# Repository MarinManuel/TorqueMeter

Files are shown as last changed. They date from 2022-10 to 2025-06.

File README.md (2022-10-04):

# Torque Meter
A low-cost, Open-Source device to evaluate hypertonia in a rabbit model of cerebral palsy
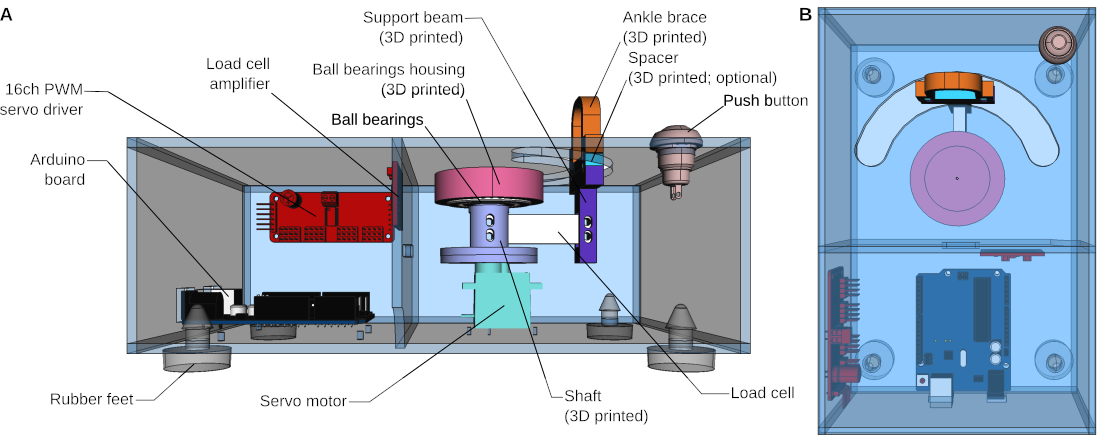
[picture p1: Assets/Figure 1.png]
A 3D model of the finished device


## Files
 - Schematics.fzz - Schematics of the electronics, Fritzing format
 - Schematics.svg - svg export of the above
 - enclosure.svg - file for laser cutter
 - Torque Meter 3D Model.FCStd - CAD files for the hardware.
                                 FreeCAD v.0.20 format
 - 3D print/ - folder containing the STL files for 3D printing the hardware
               components. Exported from the file above
 - Assets/ - contains datasheets and other misc. Files
 - ArduinoTorqueMeter/ - the main Arduino Sketch
 - CalibTorqueMeter/ - Arduino sketch for calibrating the load cell output
 - TorquePlotter/ - Python software for capturing and plotting data from the
                    Torque Meter

## LICENSES
Copyright Preston Steel, Marin Manuel 2022
### Hardware
This source describes Open Hardware and is licensed under the CERN-OHL-S v2.You may redistribute and modify this source and make products using it under the terms of the CERN-OHL-S v2 (https://ohwr.org/cern_ohl_s_v2.txt).This source is distributed WITHOUT ANY EXPRESS OR IMPLIED WARRANTY, INCLUDING OF MERCHANTABILITY, SATISFACTORY QUALITY AND FITNESS FOR A PARTICULAR PURPOSE. Please see the CERN-OHL-S v2 for applicable conditions.
As per CERN-OHL-S v2 section 4, should You produce hardware based on this source, You must where practicable maintain the Source Location visible on the external case of the Gizmo or other products you make using this source.
## Software         
The Torque Meter software is free software: you can redistribute it and/or modify it under the terms of the GNU General Public License as published by the Free Software Foundation, either version 3 of the License, or (at your option) any later version.

The Torque Meter software is distributed in the hope that it will be useful, but WITHOUT ANY WARRANTY; without even the implied warranty of MERCHANTABILITY or FITNESS FOR A PARTICULAR PURPOSE. See the GNU General Public License for more details.

You should have received a copy of the GNU General Public License along with the Torque Meter software. If not, see <https://www.gnu.org/licenses/>.

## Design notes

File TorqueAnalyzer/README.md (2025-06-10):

# Torque Analyzer
a GUI for manual curation of the torque data files



# Usage
When first run, the software displays this screen:



Use the `Result File...` button to create a new result Excel file (or open an existing one).



Then, use the `Load data files...` button to open the root folder containing all the data files to analyze (this should be the folder containing all the experiment folders with the date as the the folder name)



Click on the "Start" button to start the process.



The software then displays the first file



When anlyzing a file, you have the option to:

- remove outliers by clicking the `Remove Outliers` check box (or press the `o` key).





- remove specific movement cycles from the analysis by double clicking on the shaded areas in the top two plot areas





- reject the file altogether by clicking the red button (or press the `r` key). The software automatically moves to the next file in the list.

For instance, this file should be rejected because it does not contain enough cycles



- when you are happy with your analysis, click the green button (or press the `a` key). The software automatically moves to the next file in the list.



The software automatically updates the data in the result file. You can restart your analysis where you left off by restarting the software and loading the previously-started result Excel file. Files already analyzed are not loaded unless the box `Skip already analyzed files` is unchecked.

# Resources
<a target="_blank" href="https://icons8.com/icon/4r5HpCBBbNn8/next-page">Next</a> icon by <a target="_blank" href="https://icons8.com">Icons8</a>. <a target="_blank" href="https://icons8.com/icon/LeIi2nYOolQt/back-to">Previous</a> icon by <a target="_blank" href="https://icons8.com">Icons8</a>. <a target="_blank" href="https://icons8.com/icon/Y5jV4wJL13np/open-folder">Open Folder</a> icon by <a target="_blank" href="https://icons8.com">Icons8</a>

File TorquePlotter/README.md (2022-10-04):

TorquePlotter is a minimal software allowing to record and plot in real-time
the data generated by the Torque Meter.

# Installation

# Usage

# Installation from source
 - create a python environment
   - Install miniconda (python 3.9)
   - open miniconda shell
   - run:
```
$ conda env create --file environment.yml
$ conda activate torque
```
   - cd to the `TorquePlotter` directory
   - run
```
$ python TorquePlotter.py
```

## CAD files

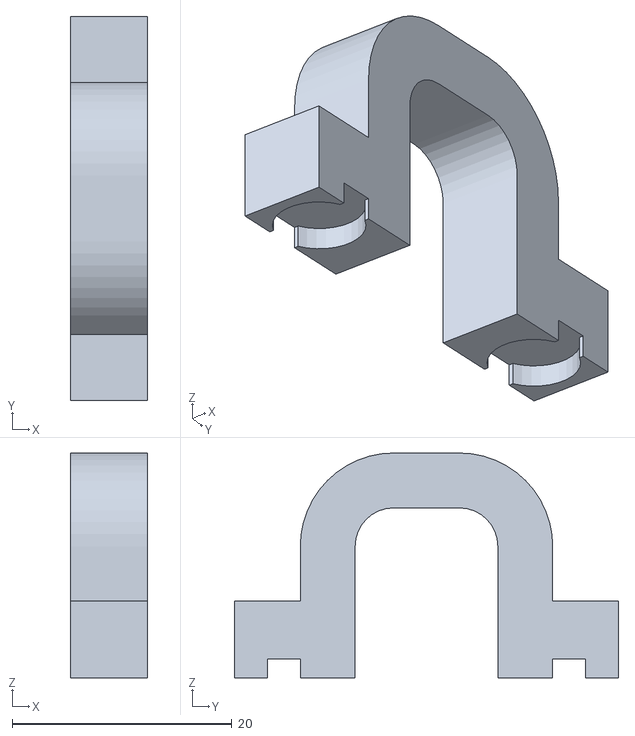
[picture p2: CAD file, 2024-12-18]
3D print/Holder-Small.stl
7.00 x 35.0 x 20.5

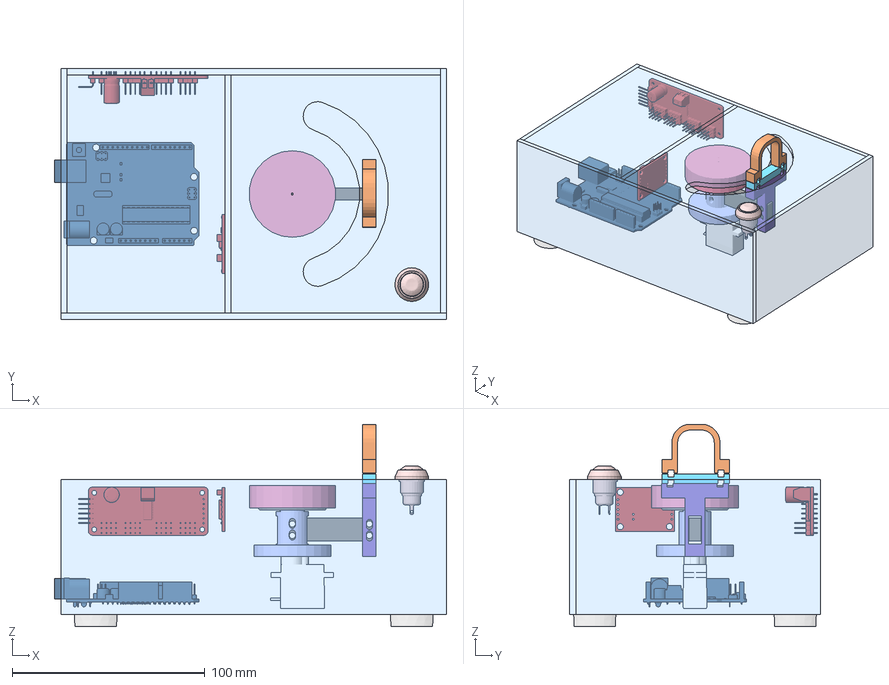
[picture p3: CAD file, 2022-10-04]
Torque Meter 3D Model.FCStd
203.4 x 130.0 x 105.0 mm
Enclosure - top
Enclosure - left
Enclosure - bottom
Enclosure - right
Enclosure - back
Enclosure - partition
Arduino
Support Beam
Spacer
Load cell
Shaft
Ankle brace
Ball bearing housing
button
foot 1
foot 2
foot 3
foot 4
PCA9685
HX711 V2
Ball bearings
Enclosure - front
Servo

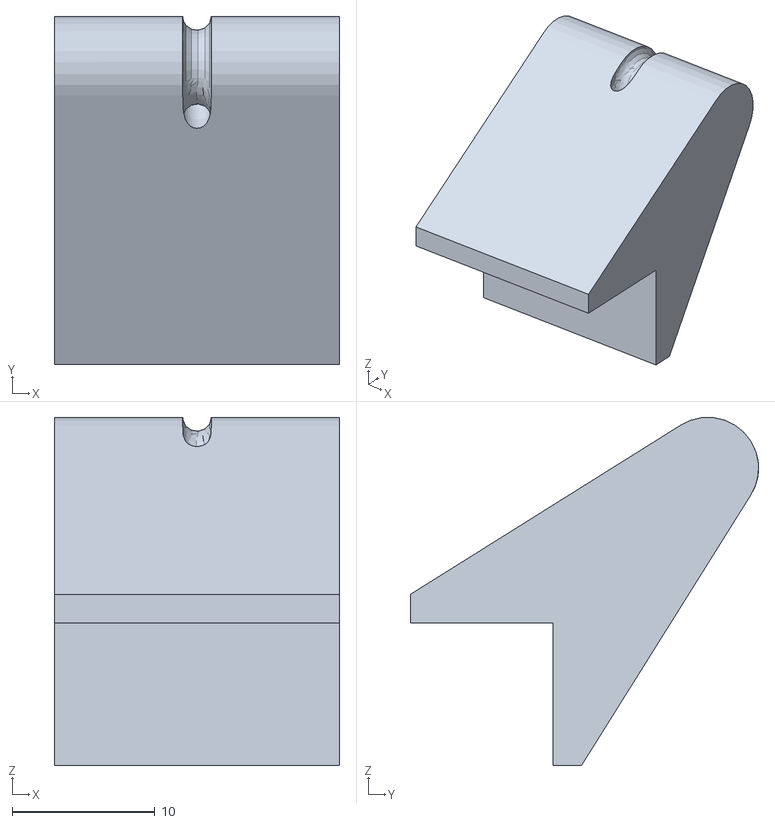
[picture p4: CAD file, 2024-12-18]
3D print/pulley.stl
20.0 x 24.4 x 24.4

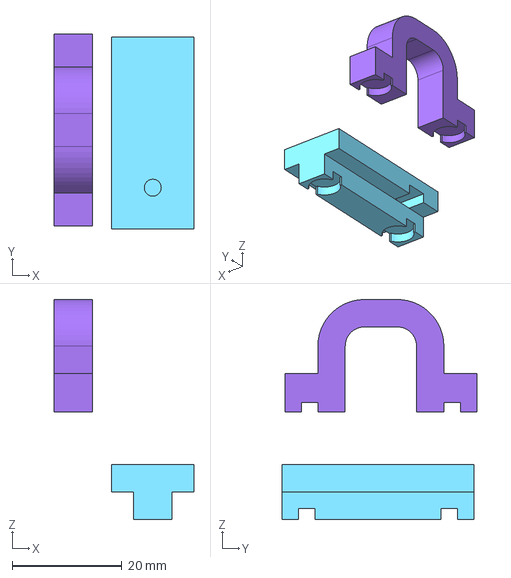
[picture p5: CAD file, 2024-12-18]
3D print/3D printed pieces.FCStd
25.5 x 35.5 x 40.1 mm
Ankle Brace Small
Spacer-strap

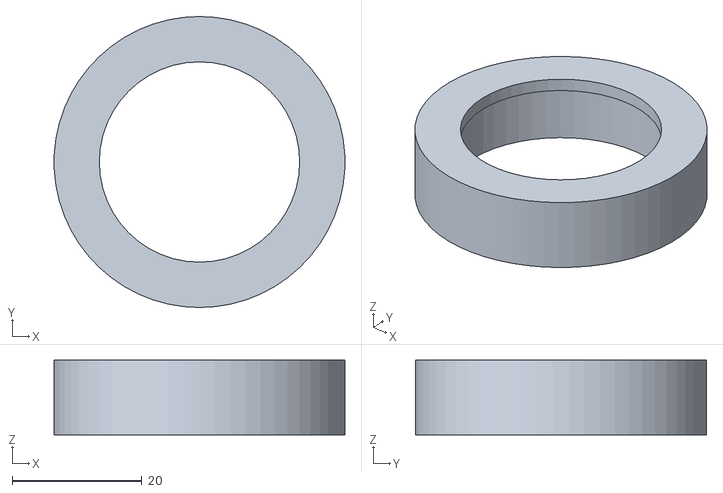
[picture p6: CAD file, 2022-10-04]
3D print/Bearing ring.stl
44.9 x 44.9 x 11.5

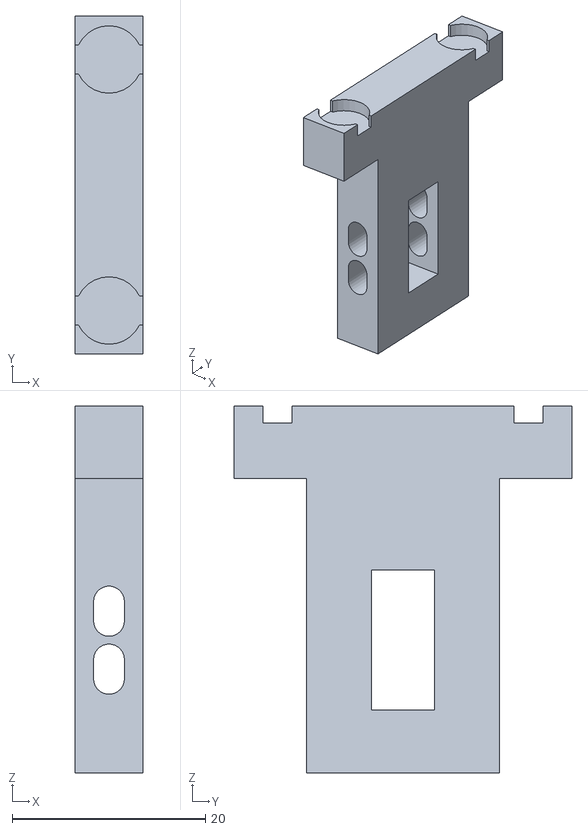
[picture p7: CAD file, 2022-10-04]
3D print/Tbar.stl
7.00 x 35.0 x 38.0

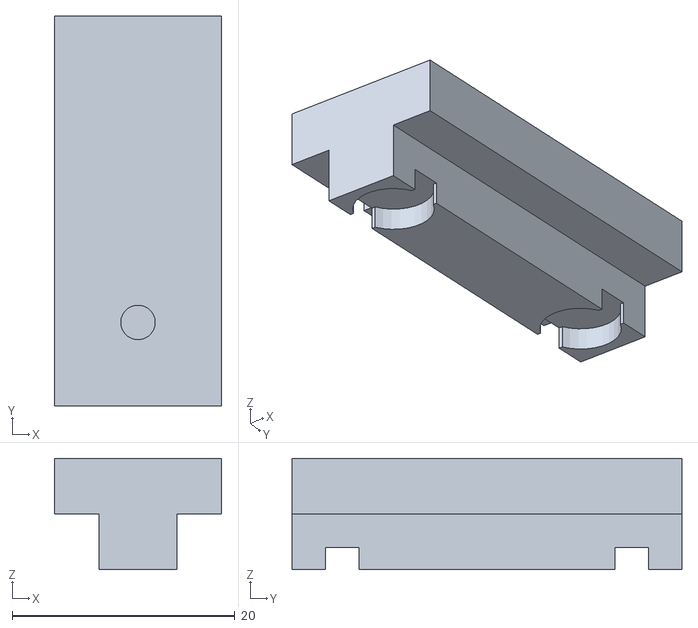
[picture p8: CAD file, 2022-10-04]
3D print/Spacer-strap.stl
15.0 x 35.0 x 10.0

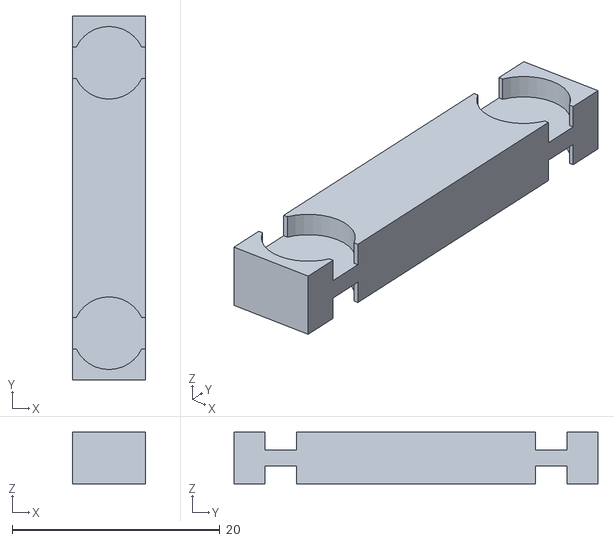
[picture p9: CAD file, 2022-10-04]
3D print/Spacer.stl
7.00 x 35.0 x 5.00

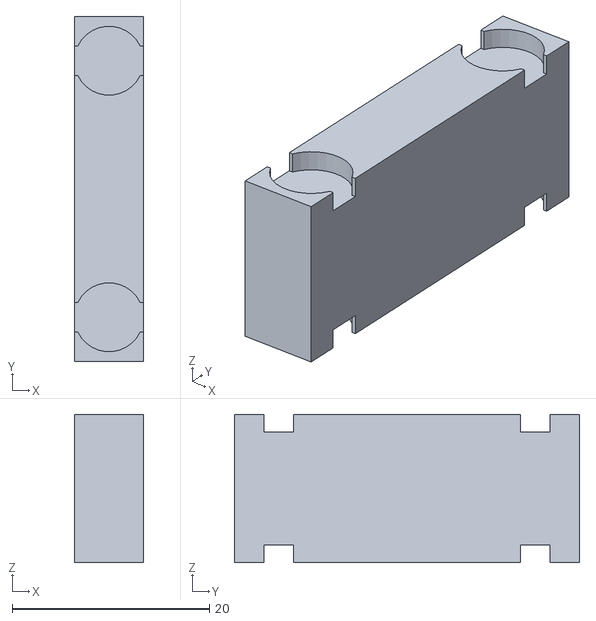
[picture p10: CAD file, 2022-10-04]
3D print/Spacer-3.stl
7.00 x 35.0 x 15.0

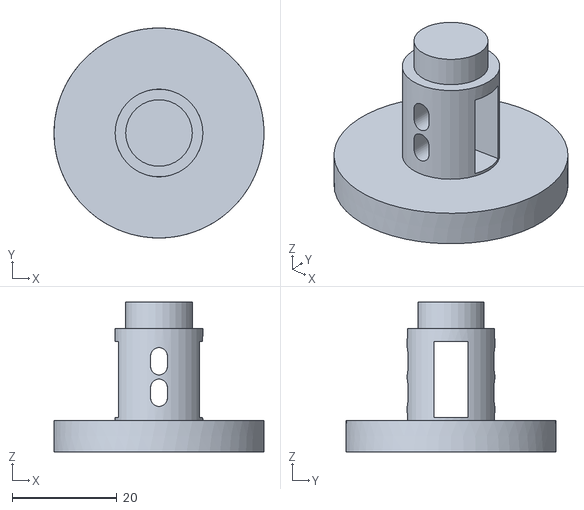
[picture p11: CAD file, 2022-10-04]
3D print/Shaft.stl
40.0 x 40.0 x 28.5

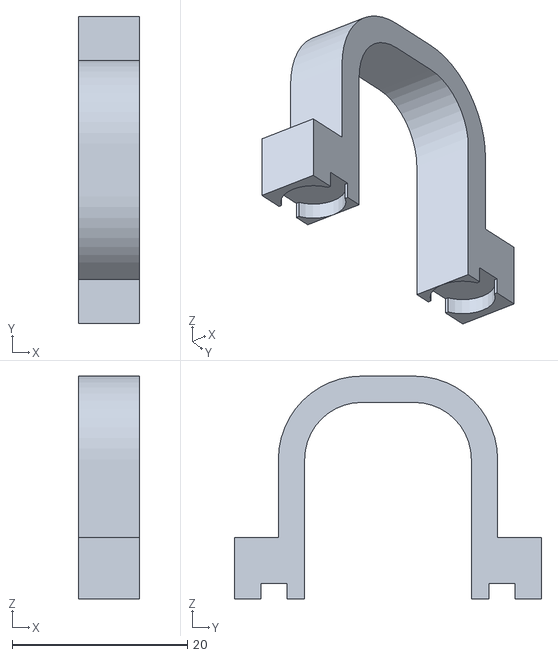
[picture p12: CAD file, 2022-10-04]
3D print/Holder-Large.stl
7.00 x 35.0 x 25.4

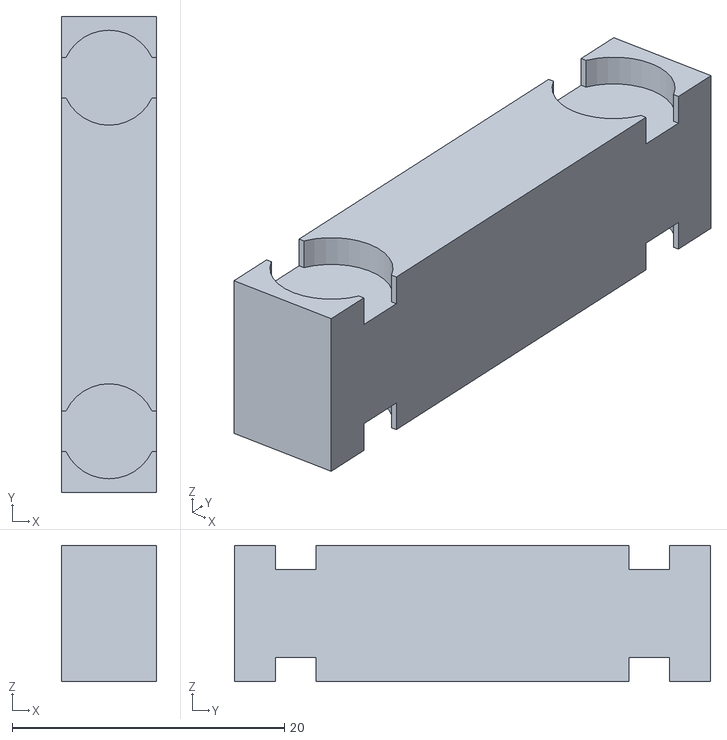
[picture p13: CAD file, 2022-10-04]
3D print/Spacer-2.stl
7.00 x 35.0 x 10.0

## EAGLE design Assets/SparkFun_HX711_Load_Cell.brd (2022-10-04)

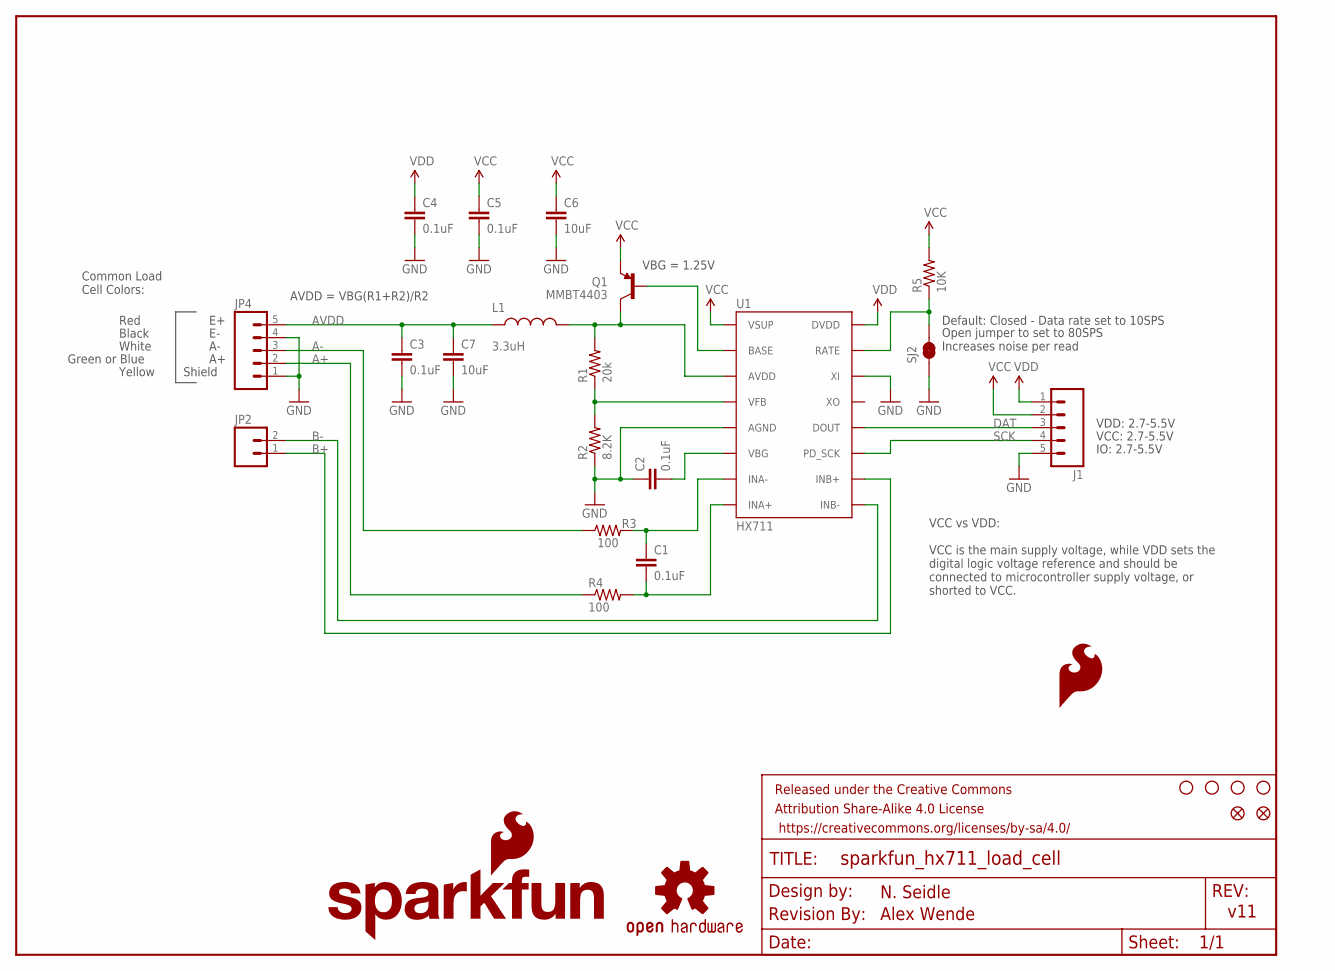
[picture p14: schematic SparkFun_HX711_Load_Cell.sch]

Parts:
C1, C2, C3, C4, C5: 0.1uF; 0603-CAP
C6, C7: 10uF; 1210
FID1, FID2: FIDUCIAL1X2; FIDUCIAL-1X2
FRAME1: FRAME-LETTER; CREATIVE_COMMONS
J1: M05PTH; 1X05
JP2: M02PTH; 1X02
JP4: M05PTH; 1X05
L1: 3.3uH; 0805
LOGO1: SFE_LOGO_NAME_FLAME.1_INCH; SFE_LOGO_NAME_FLAME_.1
LOGO3: SFE_LOGO_FLAME.1_INCH; SFE_LOGO_FLAME_.1
Q1: MMBT4403; SOT23-3
R1: 20k; 0603-RES
R2: 8.2K; 0603-RES
R3, R4: 100; 0603-RES
R5: 10K; 0603-RES
SJ2: JUMPER-PAD-2-NC_BY_TRACE; PAD-JUMPER-2-NC_BY_TRACE_YES_SILK
STANDOFF1, STANDOFF2, STANDOFF3, STANDOFF4: STAND-OFF
U1: HX711; SO16
U7: OSHW-LOGOS; OSHW-LOGO-S
U$1: REVISION

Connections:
A+: JP4.2, R4.1
A-: JP4.3, R3.1
AVDD: C3.1, C7.1, JP4.5, L1.1
B+: JP2.1, U1.10 (INB+)
B-: JP2.2, U1.9 (INB-)
DAT: J1.3, U1.12 (DOUT)
GND: C2.1, C3.2, C4.2, C5.2, C6.2, C7.2, J1.5, JP4.1, JP4.4, R2.1, SJ2.1, U1.5 (AGND), U1.14 (XI)
unnamed: R5.1, SJ2.2, U1.15 (RATE)
unnamed: C1.1, R3.2, U1.7 (INA-)
unnamed: C1.2, R4.2, U1.8 (INA+)
unnamed: Q1.1 (B), U1.2 (BASE)
unnamed: L1.2, Q1.3 (C), R1.2, U1.3 (AVDD)
unnamed: R1.1, R2.2, U1.4 (VFB)
unnamed: C2.2, U1.6 (VBG)
SCK: J1.4, U1.11 (PD_SCK)
VCC: C5.1, C6.1, J1.2, Q1.2 (E), R5.2, U1.1 (VSUP)
VDD: C4.1, J1.1, U1.16 (DVDD)

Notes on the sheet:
VCC: 2.7-5.5V
VBG = 1.25V
AVDD = VBG(R1+R2)/R2
Default: Closed - Data rate set to 10SPS
Open jumper to set to 80SPS Increases noise per read
Red
Black
White
Green or Blue
Common Load Cell Colors:
IO: 2.7-5.5V
Shield
Yellow
VDD: 2.7-5.5V
VCC vs VDD: VCC is the main supply voltage, while VDD sets the digital logic voltage reference and should be connected to microcontroller supply voltage, or shorted to VCC.
Alex Wende
N. Seidle
v11

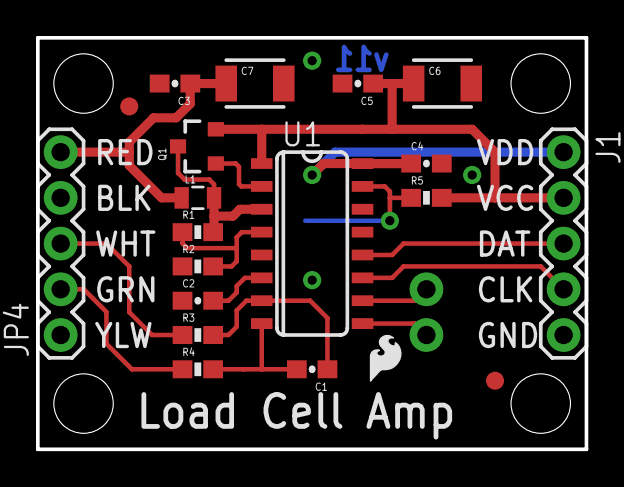
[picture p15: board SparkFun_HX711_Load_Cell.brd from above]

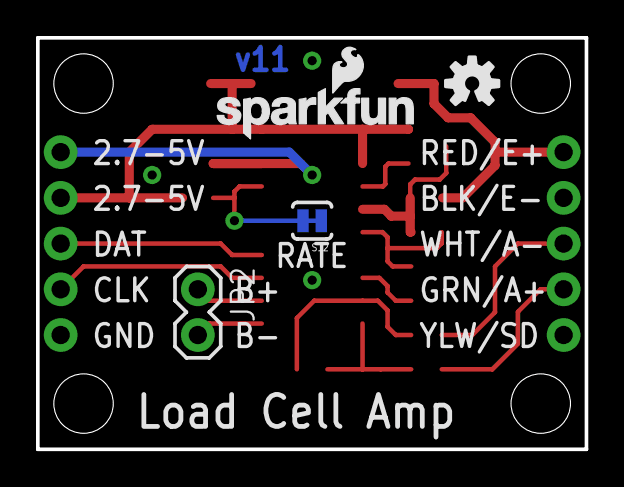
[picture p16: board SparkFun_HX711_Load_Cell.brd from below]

Board: 2 copper layers, 30.5 x 22.9 mm, 30 parts (4 on the bottom side), 17 nets.

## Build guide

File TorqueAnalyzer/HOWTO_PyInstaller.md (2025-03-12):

[Tutorial](https://www.pythonguis.com/tutorials/packaging-pyside6-applications-windows-pyinstaller-installforge/) for PyInstaller

# Create exe with PyInstaller
In Windows virtual box, open conda, activate GUI env, run:
```shell
pyinstaller TorqueAnalyzer.spec
```

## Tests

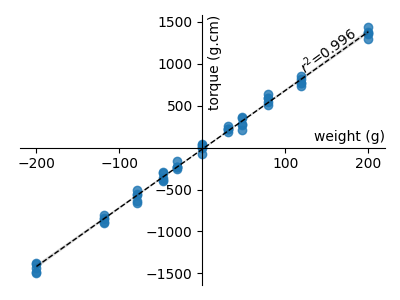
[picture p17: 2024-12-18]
Assets/calibration.png

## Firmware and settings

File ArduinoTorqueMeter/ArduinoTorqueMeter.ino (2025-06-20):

/***************************************************
  This is the sketch for controlling the Torque Meter

  Required libraries:
  - HX711
  - Adafruit_PWMServoDriver
 ****************************************************/


#include <Wire.h>
#include <Adafruit_PWMServoDriver.h>
#include <HX711.h>


/****************** GLOBAL PARAMETERS ***************
    These parameters may need to be adjusted for your build
 ****************************************************/
#define PWM_ADDRESS 0x40   // I2C Address of the PWM board
#define SERVO_PIN 0       // Servo pins on the PWM board












#define BAUDRATE 115200   // Serial Baudrate -- Make sure program on computer uses same values
//#define DEBUG
/**** PWM / Servo ****/
#define PWM_INTERNAL_CLOCK 26600000  // Calib MM 2025-05-01 -- The int.osc. for the PCA9685 chip is not very precise. Adjust this value so that the PWM frequency match the SERVO_FREQ
#define SERVO_FREQ 50 // Analog servos run at ~50 Hz updates
#define SERVOMIN 100 // This is the 'minimum' pulse length count (out of 4096) -- Different servos might need different values
#define SERVOMIN_ANGLE 0  // This is the corresponding minimum angle 
#define SERVOMAX 470 // This is the 'maximum' pulse length count (out of 4096)
#define SERVOMAX_ANGLE 180 // this is the corresponding maximum angle
#define ANGLE_BASE 90  // This is the angle at which the device idles
#define ANGLE_MAX 135  // this is the angle at the end of the movements
#define ANGLE_MIN 45  // this is the angle at the other end
#define CYCLE_PERIOD 1000 // duration that the whole cycle should take (in ms)
/*****  load cell *****/
#define CALIBRATION_FACTOR 11807.45  // use CalibTorqueMeter sketch to get this value 
/***** Arduino Pins
    Make sure those match the physical circuit */
#define LOADCELL_DOUT_PIN  3
#define LOADCELL_CLK_PIN  2
#define BTN_PIN 11

Adafruit_PWMServoDriver pwm = Adafruit_PWMServoDriver(PWM_ADDRESS, Wire);
HX711 cell;

float angle;
const float angle_rate = float(ANGLE_MAX - ANGLE_MIN) / (CYCLE_PERIOD / 2);

//setup loop to be run once on start up
void setup()
{
  //initialize load cell
  cell.begin(LOADCELL_DOUT_PIN, LOADCELL_CLK_PIN);
  cell.set_scale(CALIBRATION_FACTOR);

  //initialize button
  pinMode(BTN_PIN, INPUT);
  digitalWrite(BTN_PIN, HIGH); //turn on internal pullup

  // initialize servo
  pwm.begin();
  pwm.setOscillatorFrequency(PWM_INTERNAL_CLOCK);
  pwm.setPWMFreq(SERVO_FREQ);


  helloWorld(); // the servo waves to say hi!
  delay(100);
  angle = ANGLE_BASE;
  pwm.setPWM(SERVO_PIN, 0, pwmFromAngle(angle)); //bring servo to its baseline angle and wait for button push

  //initialize serial
  Serial.begin(BAUDRATE); //make sure this matches the data rate set in PLXDAQ!
  Serial.println("ArduinoTorqueMeter sketch");
#ifdef DEBUG
  Serial.print("angle rate is ");
  Serial.println(angle_rate);
#endif
  Serial.println("CLEARDATA");
  Serial.println("LABEL, comp time, angle, Force (g)"); //Set up first row of spreadsheet for label names
  Serial.println("RESETTIMER");

  cell.tare();
}


void loop() {
  if (digitalRead(BTN_PIN)==LOW) {
    moveServoAndReadCell(ANGLE_BASE, ANGLE_MAX, angle_rate);
    moveServoAndReadCell(ANGLE_MAX, ANGLE_MIN, angle_rate);
    moveServoAndReadCell(ANGLE_MIN, ANGLE_BASE, angle_rate);
  }
}

void outputData(float angle, float load) {
  Serial.print("DATA,");
  Serial.print(millis());
  Serial.print(",");
  Serial.print(angle);
  Serial.print(",");
  Serial.println(load);
}

void helloWorld() {
  const int Nrep = 3;
  const float angle_step = 10;
  const int del = 20;
  for (int rep = 0; rep < Nrep; rep++) {
    for (float angle = ANGLE_BASE; angle <= ANGLE_MAX; angle += angle_step) {
      pwm.setPWM(SERVO_PIN, 0, pwmFromAngle(angle));
      delay(del);
    }
    for (float angle = ANGLE_MAX; angle >= ANGLE_MIN; angle -= angle_step) {
      pwm.setPWM(SERVO_PIN, 0, pwmFromAngle(angle));
      delay(del);
    }
    for (float angle = ANGLE_MIN; angle >= ANGLE_BASE; angle -= angle_step) {
      pwm.setPWM(SERVO_PIN, 0, pwmFromAngle(angle));
      delay(del);
    }
  }
}

uint16_t pwmFromAngle(float angle) {
  /* This function takes an angle in degrees and returns
      the corresponding pulse count for the PWM board */
  if (angle <= SERVOMIN_ANGLE) {
    angle = SERVOMIN_ANGLE;
  }
  if (angle >= SERVOMAX_ANGLE) {
    angle = SERVOMAX_ANGLE;
  }
  uint16_t ret = map(angle, SERVOMIN_ANGLE, SERVOMAX_ANGLE, SERVOMIN, SERVOMAX);
#ifdef DEBUG
  Serial.print("pulse count is ");
  Serial.println(ret);
#endif
  return ret;
}

void moveServoAndReadCell(float angle_start, float angle_end, float angle_rate) {
  float load;
  unsigned long currTime = millis(), prevTime = currTime;
  float dt;
  if (angle_start < angle_end) {
    do {
      load = cell.get_units();
      outputData(angle, load);
      prevTime = currTime;
      currTime = millis();
      dt = (currTime - prevTime);
#ifdef DEBUG
      Serial.print("prevTime=");
      Serial.print(prevTime);
      Serial.print(", currTime=");
      Serial.print(currTime);
      Serial.print(", dt=");
      Serial.println(dt);
#endif
      angle += angle_rate * dt;
      pwm.setPWM(SERVO_PIN, 0, pwmFromAngle(angle));
    } while (angle < angle_end);
  } else {
    do {
      load = cell.get_units();
      outputData(angle, load);
      prevTime = currTime;
      currTime = millis();
      dt = (currTime - prevTime);
#ifdef DEBUG
      Serial.print("prevTime=");
      Serial.print(prevTime);
      Serial.print(", currTime=");
      Serial.print(currTime);
      Serial.print(", dt=");
      Serial.println(dt);
#endif
      angle -= angle_rate * dt;
      pwm.setPWM(SERVO_PIN, 0, pwmFromAngle(angle));
    } while (angle > angle_end);
  }
}

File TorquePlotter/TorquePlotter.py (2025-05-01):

# TorquePlotter.py
# Quick and dirty GUI for reading incoming serial port data from the Torque Meter
# plotting the data and saving it as csv file
import argparse
import logging
import typing
from io import StringIO
from pathlib import Path

import numpy as np
import pyqtgraph as pg
import pyqtgraph.exporters
import serial
from PyQt5 import uic
from PyQt5.QtCore import QTimer
from PyQt5.QtGui import QCloseEvent
from PyQt5.QtWidgets import (
    QPushButton,
    QLineEdit,
    QComboBox,
    QPlainTextEdit,
    QStatusBar,
    QFileDialog,
    QGroupBox,
    QMessageBox,
    QMainWindow,
    QApplication,
    QAction,
    QSpinBox,
    QButtonGroup,
    QDoubleSpinBox,
    QRadioButton,
)
from serial.tools import list_ports

UPDATE_PERIOD = 100  # in ms
FILE_NAME_TEMPLATE = "{ID}_P{Age:d}_{Limb}_{Speed}s{Comments}"

logger = logging.getLogger("TorquePlotter")
handler = logging.StreamHandler()
# noinspection SpellCheckingInspection
formatter = logging.Formatter("%(asctime)s - %(name)s - %(levelname)s - %(message)s")
handler.setFormatter(formatter)
logger.addHandler(handler)
LOGGING_LEVELS = [logging.NOTSET, logging.WARNING, logging.INFO, logging.DEBUG]


class MainWindow(QMainWindow):
    infoGroupBox: QGroupBox
    serialGroupBox: QGroupBox
    startButton: QPushButton
    stopButton: QPushButton
    serialConnectButton: QPushButton
    rootPathEdit: QLineEdit
    refreshSerialButton: QPushButton
    browseButton: QPushButton
    baudRateComboBox: QComboBox
    subjectIDEdit: QLineEdit
    subjectAgeSpinBox: QSpinBox
    limbButtonGroup: QButtonGroup
    subjectLimbFLRadioButton: QRadioButton
    subjectLimbFRRadioButton: QRadioButton
    subjectLimbHLRadioButton: QRadioButton
    subjectLimbHRRadioButton: QRadioButton
    subjectSpeedSpinBox: QDoubleSpinBox
    subjectCommentsEdit: QLineEdit
    serialOutputWidget: QPlainTextEdit
    serialPortsComboBox: QComboBox
    plotView: pg.PlotWidget
    # noinspection SpellCheckingInspection
    statusbar: QStatusBar
    action_Quit: QAction
    action_Open: QAction
    serial: typing.Union[None, serial.Serial]

    def __init__(self) -> None:
        # noinspection PyArgumentList
        super(MainWindow, self).__init__()
        uic.loadUi(
            Path(__file__).parent.resolve() / "ui_mainwindow.ui", self
        )  # Load the .ui file

        self.subjectIDMissingStylesheet = "background:red"

        self.basename = ""
        self.serial = None
        self.file = None
        self.serial_ports = []
        self.list_serial_ports()

        self.rootPath = Path.cwd()
        self.rootPathEdit.setText(self.rootPath.as_posix())

        self.refreshSerialButton.clicked.connect(self.list_serial_ports)
        self.browseButton.clicked.connect(self.browse_root_path)
        self.serialConnectButton.clicked.connect(self.connect_serial)
        self.startButton.clicked.connect(self.start)
        self.stopButton.clicked.connect(self.stop)
        self.action_Open.triggered.connect(self.action_open_file)
        self.action_Quit.triggered.connect(self.close)
        self.subjectIDEdit.textEdited.connect(self.subject_id_edited)

        self.LIMB_BUTTON_MAPPING = {
            self.subjectLimbFLRadioButton: "FL",
            self.subjectLimbFRRadioButton: "FR",
            self.subjectLimbHLRadioButton: "HL",
            self.subjectLimbHRRadioButton: "HR",
        }

        self.plotItem: pg.PlotItem = self.plotView.getPlotItem()
        self.plotItem.setLabels(left="Force (gf)", bottom="Angle (deg)")
        self.plotItem.showGrid(x=True, y=True, alpha=0.5)
        self.curve = self.plotItem.plot(symbol="o")
        self.data = np.ndarray(shape=(0, 2))

        self.timer = QTimer(None)
        self.timer.timeout.connect(self.update)
        self.timer.stop()

        self._serial_buffer = ""

        self.show()  # Show the GUI

    def connect_serial(self):
        if self.serialConnectButton.isChecked():
            # button is checked, connecting...
            logger.debug(
                f"Attempting to connect to {self.serialPortsComboBox.currentData().device}, "
                f"baudrate={int(self.baudRateComboBox.currentText())}"
            )
            try:
                self.serial = serial.Serial(
                    port=self.serialPortsComboBox.currentData().device,
                    baudrate=int(self.baudRateComboBox.currentText()),
                    timeout=UPDATE_PERIOD / 1000.0,
                )
                if (self.serial is None) or (not self.serial.is_open):
                    raise serial.SerialException("Unexpected error")
                logger.debug(f"Serial connected to {self.serial}")
            except (ValueError, serial.SerialException) as e:
                # noinspection PyArgumentList
                QMessageBox.critical(self, "ERROR", str(e))
                return
            self.serial.reset_output_buffer()
            self.serial.reset_input_buffer()

            self.serialConnectButton.setChecked(True)
            self.serialPortsComboBox.setEnabled(False)
            self.refreshSerialButton.setEnabled(False)
            self.baudRateComboBox.setEnabled(False)
            self.infoGroupBox.setEnabled(True)
            self.startButton.setEnabled(True)
            self.statusbar.showMessage(
                f"Connected to {self.serial.port} ({self.serial.baudrate} bauds)"
            )
        else:
            # button is already checked, disconnect
            logger.debug(f"Closing serial port {self.serial}")
            if self.timer.isActive():
                logger.debug("Acquisition in progress... stopping")
                self.stop()
            if self.serial is not None:
                self.serial.close()
            self.serialConnectButton.setChecked(False)
            self.serialPortsComboBox.setEnabled(True)
            self.refreshSerialButton.setEnabled(True)
            self.baudRateComboBox.setEnabled(True)
            self.infoGroupBox.setEnabled(False)
            self.startButton.setEnabled(False)
            self.statusbar.clearMessage()

    def process_incoming_data(self, in_data, sep="\n"):
        # since we are reading the data in chunks, there is no guarantee
        # that we captured full lines, so we use a buffer and use only the full lines present in the buffer,
        # the rest remaining the buffer for the next update() call
        self._serial_buffer += in_data
        # logger.debug(f"_serial_buffer = {self._serial_buffer}")
        out_data, sep, after = self._serial_buffer.rpartition(sep)
        self._serial_buffer = after
        # logger.debug(f"kep '{self._serial_buffer}' in buffer, returning '{out_data}'")
        return out_data
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

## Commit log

2022-10-04 initial upload
    [3D printed pieces.FCStd, Bearing ring.stl, Holder-Large.stl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]
2022-10-04 added assets
    [Shaft.stl, Tbar-wide.stl, Tbar.stl]
2024-02-01 added test data
    [CyclePeriod1000.xlsx, CyclePeriod1250.xlsx, CyclePeriod1500.xlsx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]
2024-02-01 Fixed performance of TorquePlotter
    - added option to specific parameters in Filename
    [TorquePlotter.py]
2024-12-18 Torque Analyzer v0.1
2024-12-18 added pulley and calibration info
    [3D printed pieces.FCStd, Calib strain gauge.csv, Holder-Small.stl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]
2025-03-12 added validation button
2025-05-01 general fixes
    fixes discovered when replacing the force gauge on 2025-05-01
    [ArduinoTorqueMeter.ino, CalibTorqueMeter.ino, TorquePlotter.py]
2025-06-20 update calibration factor with new strain gauge

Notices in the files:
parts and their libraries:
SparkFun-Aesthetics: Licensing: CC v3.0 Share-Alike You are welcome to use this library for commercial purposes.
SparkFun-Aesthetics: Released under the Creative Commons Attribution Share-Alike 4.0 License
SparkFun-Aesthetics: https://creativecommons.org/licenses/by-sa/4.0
